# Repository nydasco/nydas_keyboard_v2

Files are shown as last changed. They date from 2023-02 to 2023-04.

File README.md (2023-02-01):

# Nydas Keyboard

This repo currently contains two primary folders:

1. NydasAmoeba - this contains both the KiCad files and the Gerber for a per-key RGB choc PCB
2. NydasDactyl - this contains (very much WIP) OpenSCD and stl files for a 3D case

A third folder will be created in the future that holds the code to flash onto a keyboard controller to make this whole thing work.

Readme.md files have been added into each of the parent folders with information on the specific item.

This is a personal project that I will be completing over a number of months, I'm in no great rush to get it completed, so please don't pin your hopes on getting a completed 'ready to go' version of this any time soon unless you want to finish it off yourself.

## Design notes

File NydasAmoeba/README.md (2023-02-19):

# Nydas Amoeba PCB

This 'per switch' PCB was designed from scratch however takes inspiration from the Amoeba King PCB. The goal was to deliver a PCB that was as small as possible that would accommodate per-key RGB, hotswap, and fit choc switches.

> Why not simply use the Amoeba King?

Simply put, I wanted the challenge of building something myself from scratch. 

> Do you have a 'how to'?

It is not my intent for others to use this PCB, however I have made it freely available on the off chance that anyone does want to. Hopefully it is fairly logical, however I've provided the below for anyone looking for extra information.

## Front
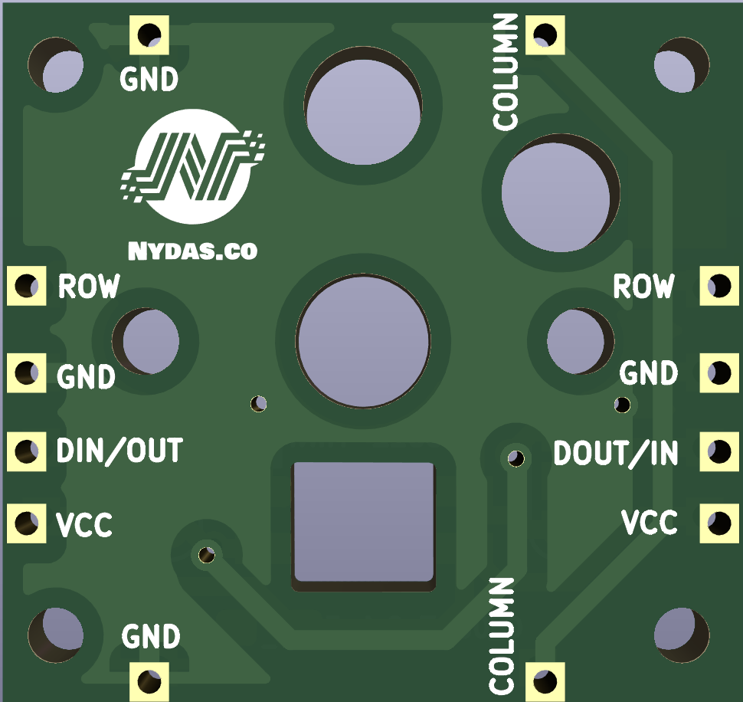
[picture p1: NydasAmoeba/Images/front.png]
Front of the PCB


The front of the board contains all of the 'text'. Nothing should be soldered to this side. It's the side that the switch will sit on. 

Each of the pins have been labelled, and I've tried to provide a number of options. For example, you can connect to Ground on all for sides (for clarity, you don't need to connect to all of the Ground points - just make sure that one of the points is connected on each board). Row connectors are on the left and right and column connectors are top and bottom. The VCC should basically be daisy chained between switches.

The complexity comes with the Data In/Out points. This can be seen on the rear of the PCB.
## Rear
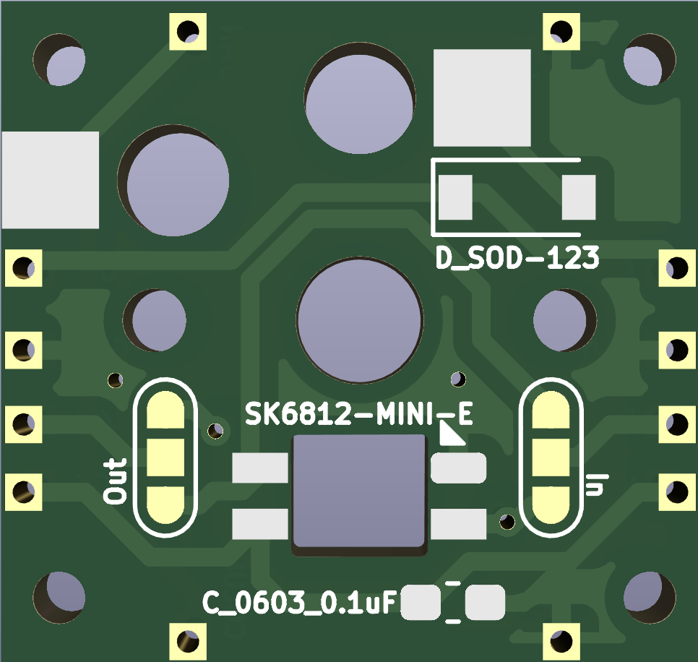
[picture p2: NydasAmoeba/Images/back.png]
Rear of the PCB


The Data In/Out points link to the three pad solder points to the left and right of the SK6812-MINI-E space. You can choose which side is In and which side is Out by bridging the connection on the appropriate pads. Looking from the rear (using the above image) if you solder the middle and bottom pads on both the left and right blocks, your Data In is on the right (left if looking from the front) and Data Out is on the right (left if looking from the front). Alternatively you can bridge the top and middle pads and the in/out will be reversed. This allows you to daisy chain along a row, and then down to the next row and daisy chain back the other way (as opposed to having to run a full length of wire across your board at the ends of each row.

The 0603 0.1uF capacitor point is likely optional. It just helps maintain power for the RGB.

## Some More Pics
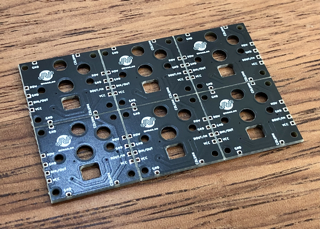
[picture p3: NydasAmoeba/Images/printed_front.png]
Printed Front

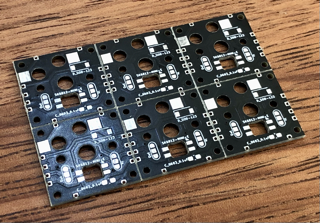
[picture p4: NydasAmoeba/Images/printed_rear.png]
Printed Rear

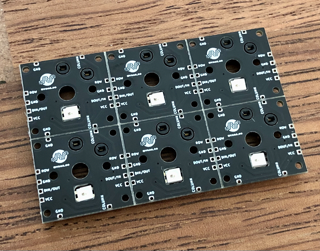
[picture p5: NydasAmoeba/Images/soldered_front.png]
Soldered Front

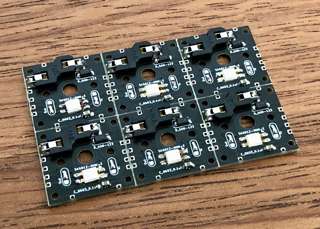
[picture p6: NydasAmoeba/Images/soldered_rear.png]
Soldered Rear

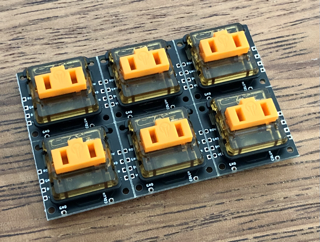
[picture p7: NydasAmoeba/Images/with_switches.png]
With Switches

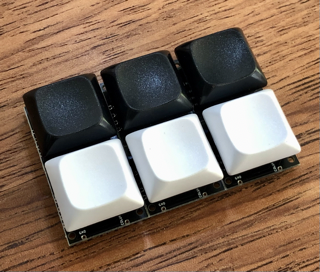
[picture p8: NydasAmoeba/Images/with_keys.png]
With Keys


> What if I don't want RGB?

Simple. If you don't want RGB, save yourself the money and effort. You can go without the capacitor and the LED. You don't need to connect the VCC or Data In/Out on any of the switches.

That's probably about all there is to it. Feel free to have a tinker in KiCad and see if you can improve on the design.

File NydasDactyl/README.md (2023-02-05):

# Nydas Dactyl
This is very much a work in progress. At this stage I have not tried to print the 3D model. Buyer beware! (don't worry - it's free)

I'm building this not as a opportunity to dive into the custom keyboard business, but simply because I wanted a challenge and I wanted a keyboard that was truly mine.

The keyboard is a split, 36 key ortho layout with a fairly aggressive stagger and a splay that mimics my fingers. I've been using a custom keyboard with the same stagger and splay, but as a 2D design for a little over 6 months now, and I figured it was time to take it to the next level.

The keyboard is designed to accommodate the Nydas Amoeba per-key PCB which also exists within the repo. It's being designed in OpenSCAD. Both the OpenSCAD files as well as an STL are available in the repo.

> What's missing?

A few things... This is an active development project, and in my mind it's not ready to print yet. While it may look 'ready', I need to work out how best to attach the top and bottom of each side together (ideally not hotglue), and I'd like to get the branding on there, but it doesn't seem to like how I'm doing it.

I'm planning to use the BlackPill controller, and when I get it programmed will create a new folder in this repo with the code to make it all work (but note that I use a modified Dvorak layout, so I'm imagining it would need some tweaking by anyone choosing to use it).

## Pictures
I'll try to keep these up to date as the design changes / more is added.
This is the front. The aim is to keep it low, but also add in a fixed tenting that works for me.
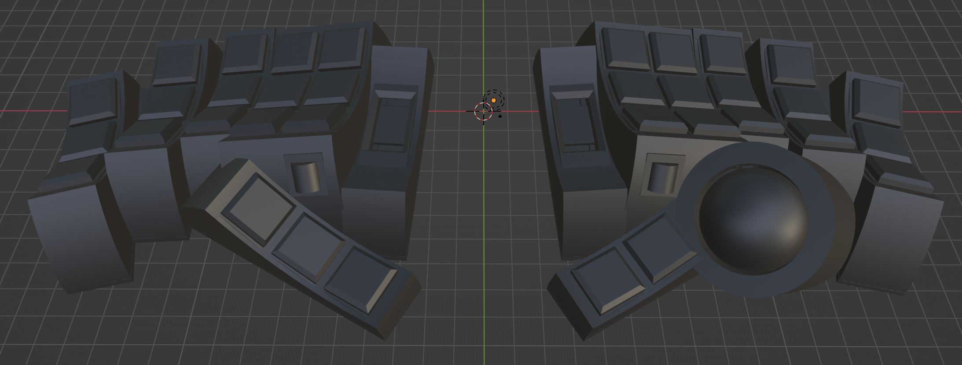
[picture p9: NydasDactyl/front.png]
Front of the keyboard

And this is the side. I've added spots for the TRRS and USB-C ports.
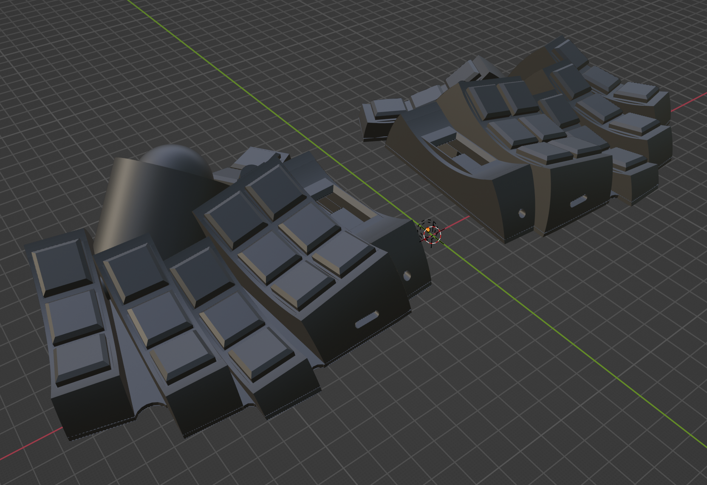
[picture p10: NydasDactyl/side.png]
Side of the keyboard


I'm not 100% sure about this right now, but I guess printing it and trying it out will tell me. Keyboards like the [Skeletyl](https://bastardkb.com/skeletyl/) curve the thumb keys the other way to the fingers (so the middle key is highest rather than lowest). I'm assuming this has been done for a good reason, and I'll waste a print finding out the hard way, but it makes sense to me that my thumb rolls the same way as my other fingers.

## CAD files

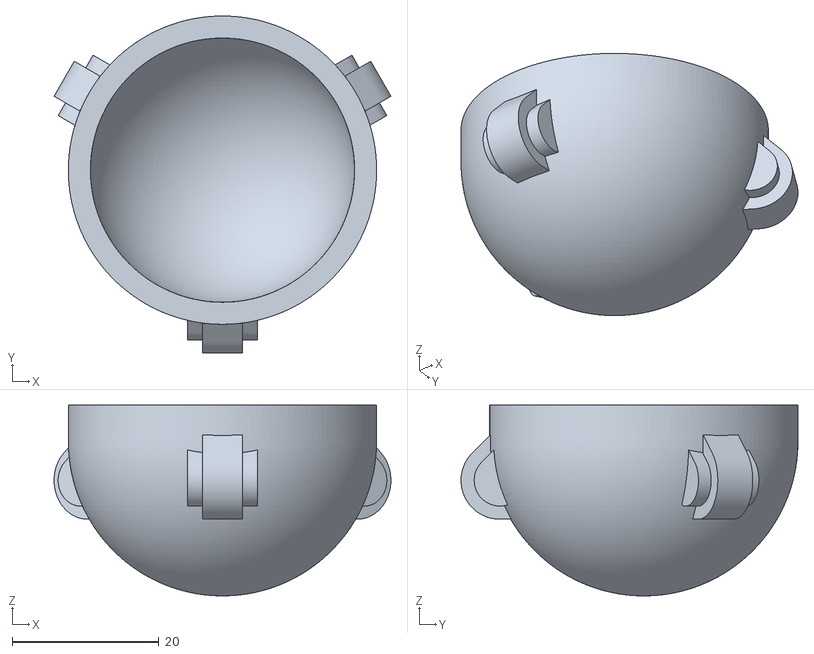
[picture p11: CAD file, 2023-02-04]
NydasDactyl/OpenSCAD/parts/trackball_socket_body_34mm.stl
45.9 x 45.9 x 26.0

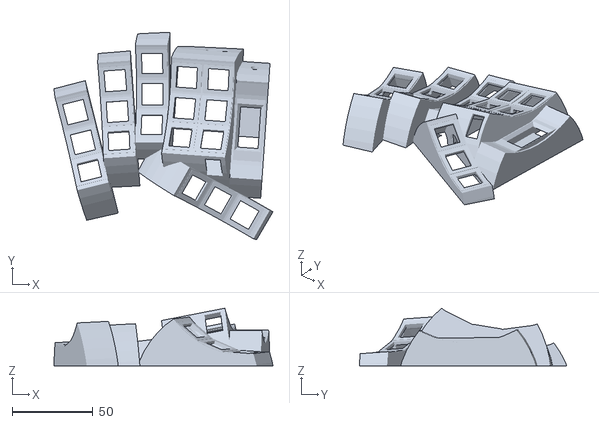
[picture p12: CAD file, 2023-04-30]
NydasDactyl/stl/left_keyboard.stl
135.5 x 128.4 x 35.6

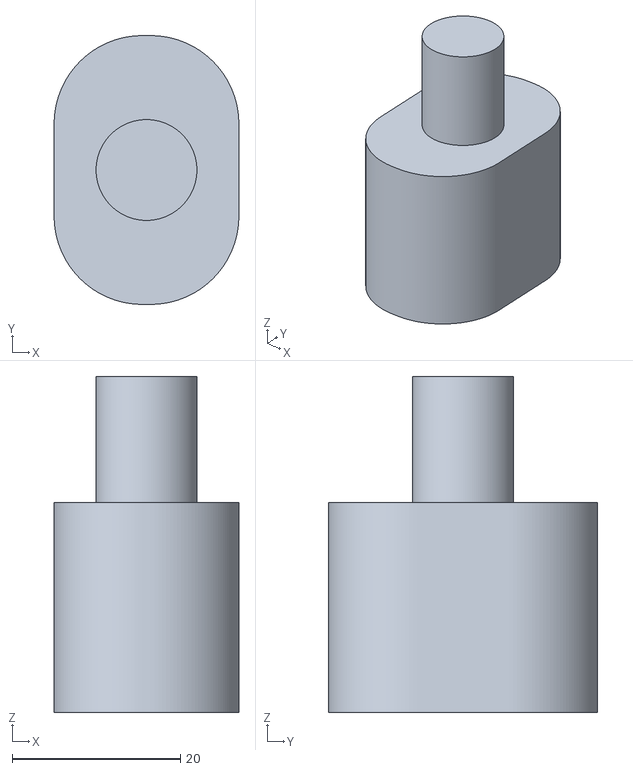
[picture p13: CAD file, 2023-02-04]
NydasDactyl/OpenSCAD/parts/trackball_sensor_cutter.stl
22.0 x 32.0 x 40.0

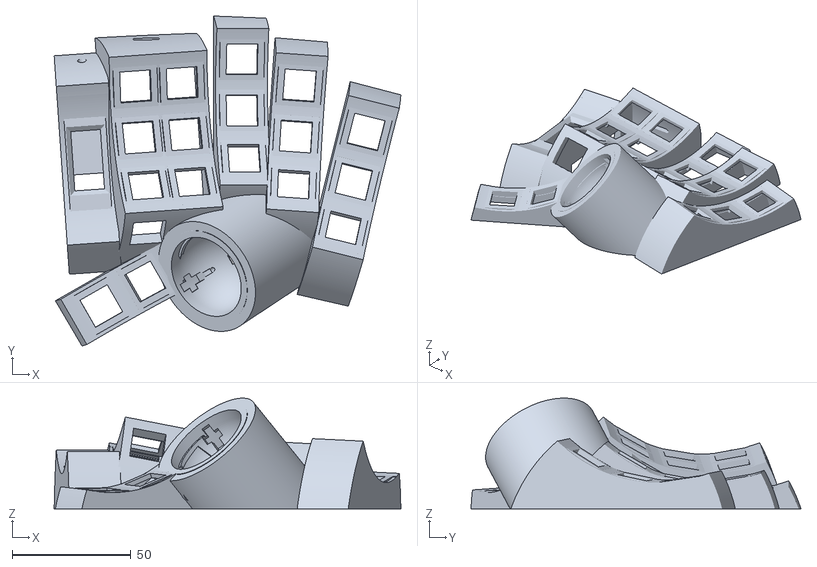
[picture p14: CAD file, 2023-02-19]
NydasDactyl/stl/right_keyboard_no_keys_fixed.stl
145.8 x 138.8 x 46.6

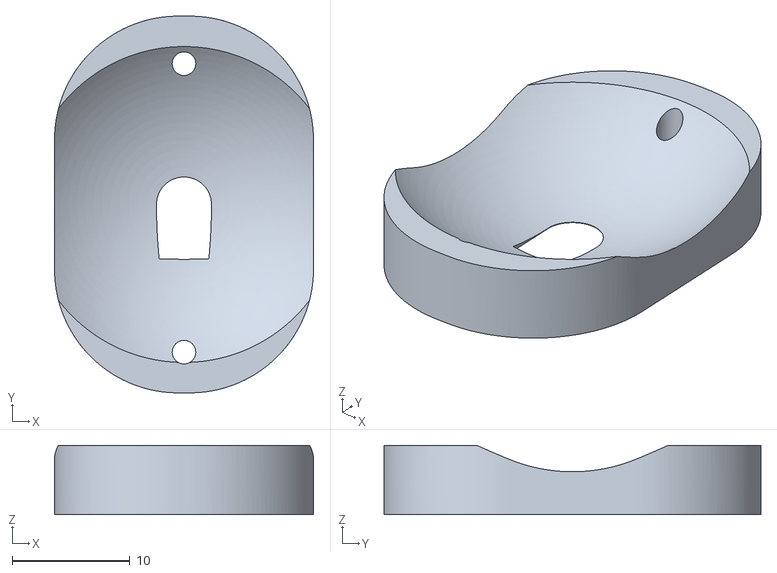
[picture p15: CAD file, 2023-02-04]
NydasDactyl/OpenSCAD/parts/trackball_sensor_mount.stl
22.0 x 32.0 x 5.90

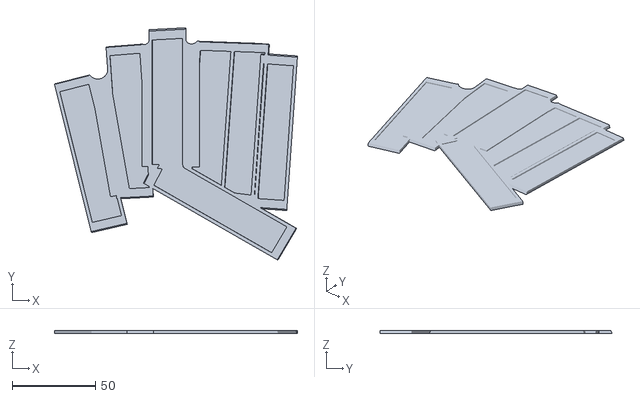
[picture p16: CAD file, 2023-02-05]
NydasDactyl/stl/base_plate_left.stl
145.8 x 139.2 x 2.00

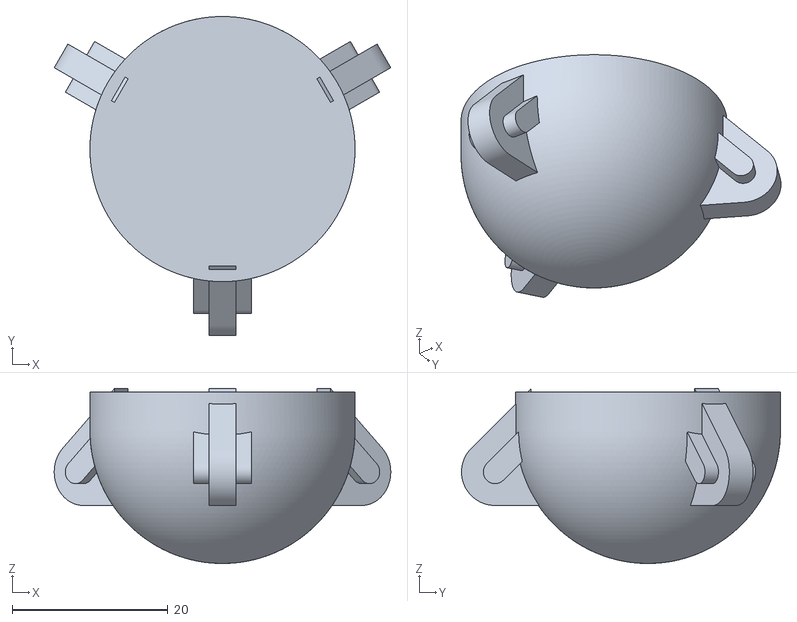
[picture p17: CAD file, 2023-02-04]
NydasDactyl/OpenSCAD/parts/trackball_socket_cutter_34mm.stl
43.2 x 40.9 x 22.4

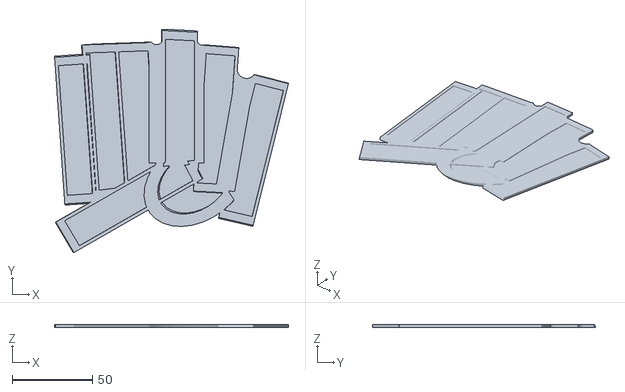
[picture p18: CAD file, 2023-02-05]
NydasDactyl/stl/base_plate_right.stl
145.8 x 139.2 x 2.00

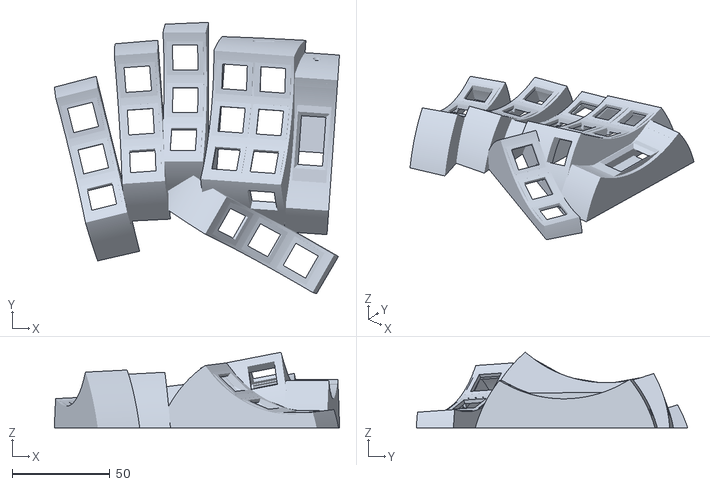
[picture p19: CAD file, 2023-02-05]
NydasDactyl/stl/left_keyboard_no_keys.stl
145.8 x 138.8 x 38.6

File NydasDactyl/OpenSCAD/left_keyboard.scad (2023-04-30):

use <main_board.scad>
use <switch_complete.scad>
use <extras.scad>
use <base_plate.scad>
use <oled_column.scad>
use <wiring_passthrough.scad>
$fn=60;
 

module all_buttons() {
    difference() {
        union() {
        // index (dbl width)
        translate([-21, -9, 8.2])
            rotate([-10, 4, 4])
            column_dbl_encoder();
        translate([-60,-22,0])
            rotate([0, -7, 4])
            oled_column(logo=false);
            
        // middle
        rotate([-3, 0, 0])
            column(full=true,wall_left = true, wall_right = true);
        };
        union(){
        // remove overlap of walls
        translate([-36, -75, 0])
            rotate([27, 0, -60])
            resize([20,0,0])
            end_wall();
        
        translate([-4,-35,-4])
            rotate([90,0,0])
            cylinder(10,5,5, center = true);
        }
    };
    // ring
    translate([21, -11, 8.2])
        rotate([-10, -4, -4])
        column(full=true,wall_left = true, wall_right = true);
    // pinky
    translate([42, -30, 11.7])
        rotate([-10, -4, -14])
        column(full=true,wall_left = true, wall_right = true);
    // thumb
    difference() {
        translate([-40, -65, 0])
            rotate([27, 0, -60])
            column(full=true,wall_left = true, wall_right = true);
        // remove overlap of walls
    translate([-4,-35,-4])
        rotate([90,0,0])
        cylinder(10,5,5, center = true);
    }

}


module main_body() {
difference() {
    union() {
        translate([0, 0, 7])
        rotate([0,7,0])
            all_buttons();
        // fix for passthrough to pinky which leaves a gap due to splay
        translate([28,-45,10])
            rotate([0,90,0])
            cylinder(1,5,5,true);
    }
    union(){
    translate([0, 0, -33])
        cube([200,200,70], center = true);
        wiring_passthrough();
        
    translate([-40,32,10])
        rotate([90,0,0])
        usb();
        
    
    translate([-63,12,10])
        rotate([280,0,0])
        trrs();
    }
    
}
}

module left_keyboard(){
mirror([180,0,0])
    union() {
        main_body();
        //ground_floor(left=true);
    }
}

left_keyboard();

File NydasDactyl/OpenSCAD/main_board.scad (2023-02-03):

use <switch_complete.scad>


$fn=360;
 

module all_buttons() {
    difference() {
        union() {
        // index (dbl width)
        translate([-25, -10, 8.2])
            rotate([-10, 4, 4])
            column_dbl();
        // middle
        rotate([-10, 0, 0])
            column();
        };
        // remove overlap of walls
        translate([-40, -71, 0])
            rotate([27, 0, -60])
            resize([20,0,0])
            end_wall();
    };
    // ring
    translate([22, -11, 8.2])
        rotate([-10, -4, -4])
        column();
    // pinky
    translate([46, -30, 11.7])
        rotate([-10, -4, -14])
        column();
    // thumb
    difference() {
        translate([-40, -71, 0])
            rotate([27, 0, -60])
            column();
        // remove overlap of walls
        rotate([-10, 0, 0])
            resize([20,0,0])
            end_wall();
    }
}


module base_plate() {
    difference() {
        union() {
        // index (dbl width)
        translate([-25, -10, 8.2])
            rotate([-10, 4, 4])
            main_posts_dbl(); 
        // middle
        rotate([-10, 0, 0])
            main_posts(); 
        };
        // remove overlap of walls
        translate([-40, -71, 0])
            rotate([27, 0, -60])
            resize([20,0,0])
            end_wall();
    };
    // ring
    translate([22, -11, 8.2])
        rotate([-10, -4, -4])
        main_posts(); 
    // pinky
    translate([46, -30, 11.7])
        rotate([-10, -4, -14])
        main_posts(); 
    // thumb
    difference() {
        translate([-40, -71, 0])
            rotate([27, 0, -60])
            main_posts(); 
        // remove overlap of walls
        rotate([-10, 0, 0])
            resize([20,0,0])
            end_wall();
    }
}



// ground floor for base
module ground_floor() {
    difference() {
        union() {
            translate([0, 0, 7])
                rotate([0,7,0])
                base_plate();
            // index
            translate([-37, -10, 0])
                rotate([0, 0, 4])
                cube([40,76,2], center = true);
            translate([-37, -30, 0])
                rotate([0, 0, 4])
                cube([40,76,2], center = true);
            // midle
            cube([20,74,2], center = true);
            translate([0,-10,0])
                cube([20,74,2], center = true);
            // ring
            translate([22, -11, 0])
                rotate([0, 0, -4])
                cube([20,74,2], center = true);
            translate([22, -21, 0])
                rotate([0, 0, -4])
                cube([20,74,2], center = true);
            // pinky
            translate([46, -30, 0])
                rotate([0, 0, -14])
                cube([20,74,2], center = true);
            translate([44, -40, 0])
                rotate([0, 0, -14])
                cube([20,74,2], center = true);
            // thumb
            translate([-40, -71, 0])
                rotate([0, 0, -60])
                cube([20,74,2], center = true);
            translate([-27, -63, 0])
                rotate([0, 0, -60])
                cube([20,74,2], center = true);
            // splay joins
            difference(){
                union(){
                translate([-15,-5,0])
                    cube([10,75.5,5], center = true);
                translate([12,-5,0])
                    cube([5,75,5], center = true);
                translate([34,-23,0])
                    rotate([0,0,-10])
                    cube([12,74.1,5], center = true);
                }
                //get bevel between fingers
                union(){
                translate([-15.2,35,0])
                    cylinder(12,4,4,center = true);
                translate([13.2,33.7,0])
                    cylinder(12,3,3,center = true);
                translate([41,16,0])
                    cylinder(12,6,6,center = true);
                }
            }
        }
        
        union() {
            translate([0, 0, -25])
                cube([200,200,50], center = true);
            translate([0, 0, 22])
                cube([200,200,40], center = true);
        }
    }
}


module wiring_passthrough() {
    translate([-35,-40,10])
        rotate([0,90,0])
        cylinder(15,5,5,true);
    translate([-25,-50,10])
        rotate([0,90,90])
        cylinder(15,5,5,true);
    translate([10,-30,10])
        rotate([0,90,0])
        cylinder(15,5,5,true);
    translate([30,-45,10])
        rotate([0,90,0])
        cylinder(15,4,4,true);
}

module main_body() {
difference() {
    union() {
        translate([0, 0, 7])
        rotate([0,7,0])
            all_buttons();
        // fix for passthrough to pinky which leaves a gap due to splay
        translate([32,-45,10])
            rotate([0,90,0])
            cylinder(4,5,5,true);
    }
    translate([0, 0, -23])
        cube([200,200,50], center = true);
        wiring_passthrough();
}
}
//translate([0,0,-10])
//    ground_floor();

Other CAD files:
NydasDactyl/stl/right_keyboard_no_keys.stl
NydasDactyl/OpenSCAD/right_keyboard.scad
NydasDactyl/OpenSCAD/base_plate.scad
NydasDactyl/OpenSCAD/extras.scad
NydasDactyl/OpenSCAD/full_render.scad
NydasDactyl/OpenSCAD/keycap.scad
NydasDactyl/OpenSCAD/oled_column.scad
NydasDactyl/OpenSCAD/right_thumb.scad
NydasDactyl/OpenSCAD/switch_complete.scad
NydasDactyl/OpenSCAD/wiring_passthrough.scad
NydasDactyl/stl/right_keyboard_no_keys_fixed.obj

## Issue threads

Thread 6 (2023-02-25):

Capacitor use

pathnirvana, 2023-02-25:
Really great design. Thank you ☺️
Can it be panelized in a 5x5 matrix?
If I omit the capacitor what would happen?

nydasco, 2023-02-25:
Certainly can't see why it wouldn't be possible to do a 5x5. It all depends on the company you use and their costings. Given you usually have to get 5 prints minimum, you'd need to have a think about the best dimensions to go with.

If you don't want RGB, no need for the capacitor. It's used to stabilise the current and ensure the LED doesn't flicker or not light if there are minute power fluctuations through the circuit. Not using them isn't going to break anything, and depending on the number of switches you may be able to get away without any, but they are 'best practice', generally with a single larger one at the start of the chain.

pathnirvana, 2023-02-25:
Many thanks for the answer
Yes the jlcpcb has a promotion for PCBs under 10×10cm area.

The reason I asked was that one of the other micropads I built with a different ameoba PCB was flickering at high brightness settings and it didn't have the capacitors

Closed 2023-02-25.

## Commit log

2023-01-30 switch to curves
    [attach.scad, bcube.scad, bevel.scad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]
2023-01-31 added walls to fingers
    [right_board.scad, switch_complete.scad]
2023-01-31 add base
    [right_board.scad, right_board.stl, switch_complete.scad]
2023-02-01 add pcb images
2023-02-01 add pcb readme
2023-02-03 add left keyboard
    [left_keyboard.scad, main_board.scad, switch_complete.scad]
2023-02-03 Added full render
    [full_render.scad]
2023-02-03 update images
    [right_board.stl]
2023-02-04 Add trackball - stage 1
    [full_render.scad, right_keyboard.scad, trackball_sensor_cutter.stl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]
2023-02-04 Add convex thumb
    [switch_complete.scad]
2023-02-05 Updated trackball
    [left_keyboard.scad, right_keyboard.scad, right_thumb.scad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]
2023-02-05 Clean up code
    [base_plate.scad, extras.scad, keycap.scad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]
2023-02-05 remove logo - too complex
    [oled_column.scad]
2023-02-05 switch logo to svg
    [base_plate.scad, left_keyboard.scad, oled_column.scad]
2023-02-05 Add stl & images & blender
    [base_plate_left.stl, base_plate_right.stl, left_keyboard.stl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]
2023-02-05 Add no-key right
    [oled_column.scad, right_keyboard_no_keys.stl, right_thumb.scad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]
2023-02-05 Add left no keys
    [left_keyboard_no_keys.stl]
2023-02-05 Set up folder structure
    [ameoba.kicad_pcb, base_plate_left.stl, base_plate_right.stl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]
2023-02-19 add images
    [right_keyboard.scad, right_keyboard_no_keys_fixed.obj, right_keyboard_no_keys_fixed.stl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]
2023-04-29 brought keys closer together
    [base_plate.scad, extras.scad, left_keyboard.scad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]
2023-04-29 cleaning alignment
    [left_keyboard.scad]
2023-04-30 fix encoder
    [left_keyboard.scad, left_keyboard.stl, switch_complete.scad]
